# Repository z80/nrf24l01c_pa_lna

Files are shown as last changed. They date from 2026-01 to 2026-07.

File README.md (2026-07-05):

# Radio board with Power Amplifier.

A 2.4GHz generic radio communication board based on NRF24L01+ Nordic radio chip and RFX2101C Power Amplifier chip.

It is equipped with an on-board 3.3V linear regulator. So, it hasn't ever been noticed loosing a connection or malfunctioning due to power rail voltage fluctuations if powered with anything above 3.7V.

Thermal design turned out to be good. At max power and constant carrier mode the board consumes ~200mA of current. But neither part gets hot. The whole board heats up evenly and is just warm on touch.

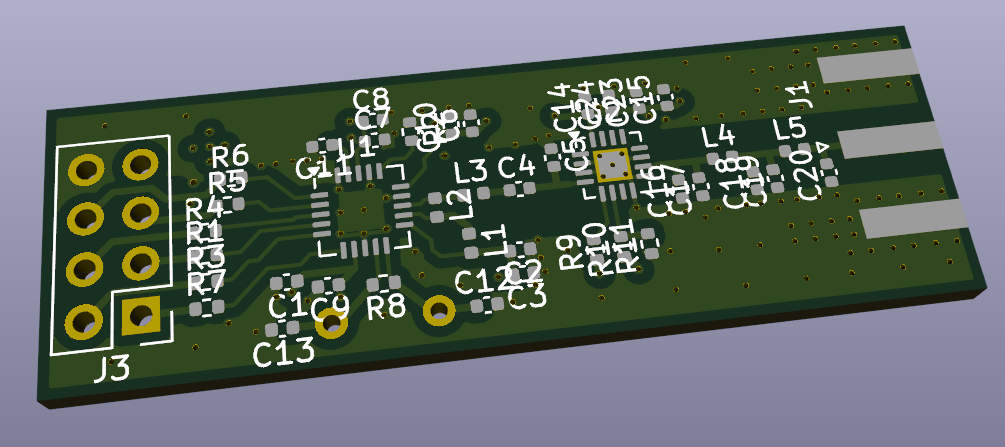
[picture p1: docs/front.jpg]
front

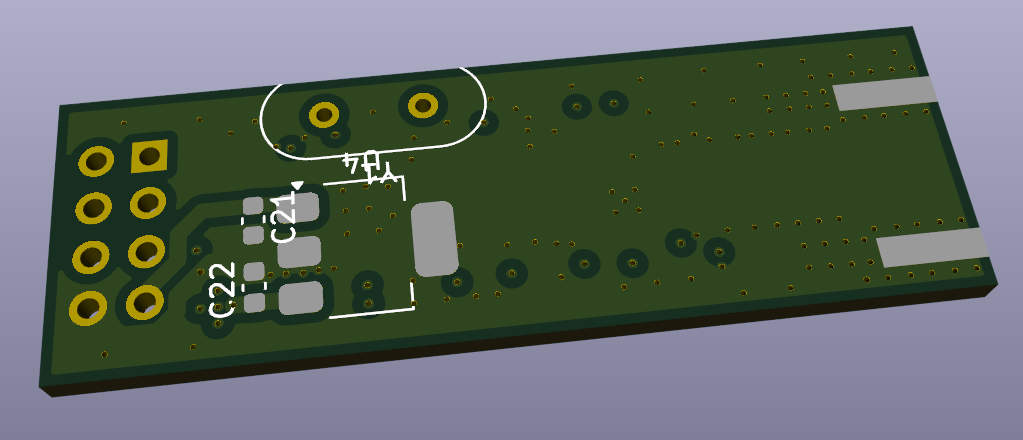
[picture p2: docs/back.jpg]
back


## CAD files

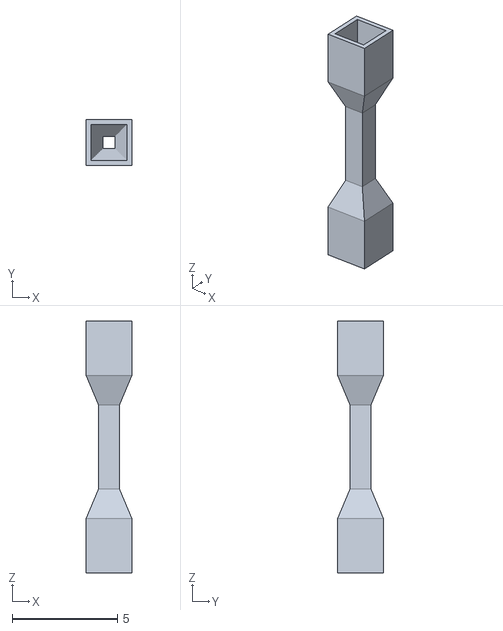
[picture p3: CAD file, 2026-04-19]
blender3d/light_stand.stl
2.17 x 2.17 x 12.0

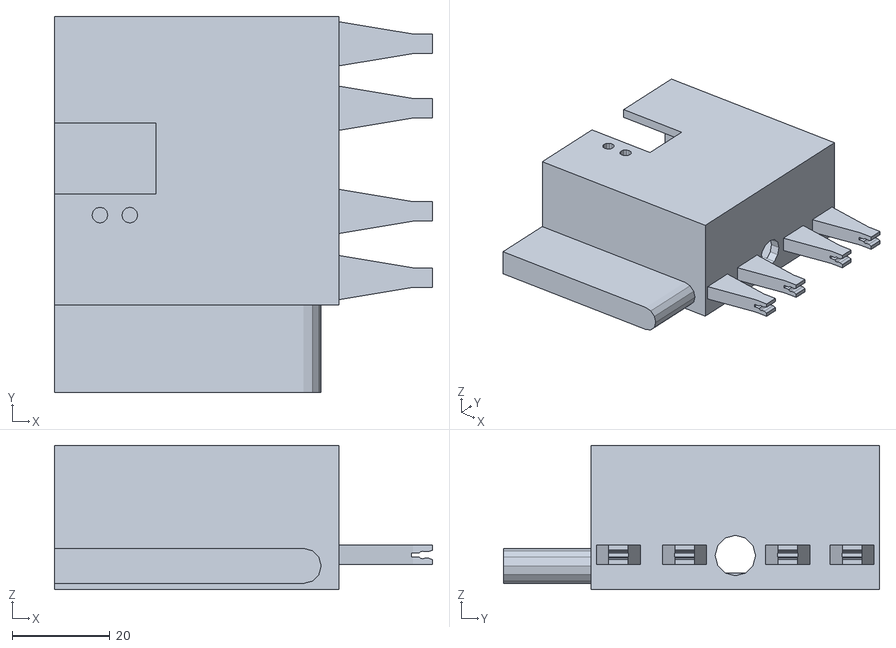
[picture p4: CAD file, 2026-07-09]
blender3d/multi/rf_outer_case.stl
77.4 x 77.1 x 29.6

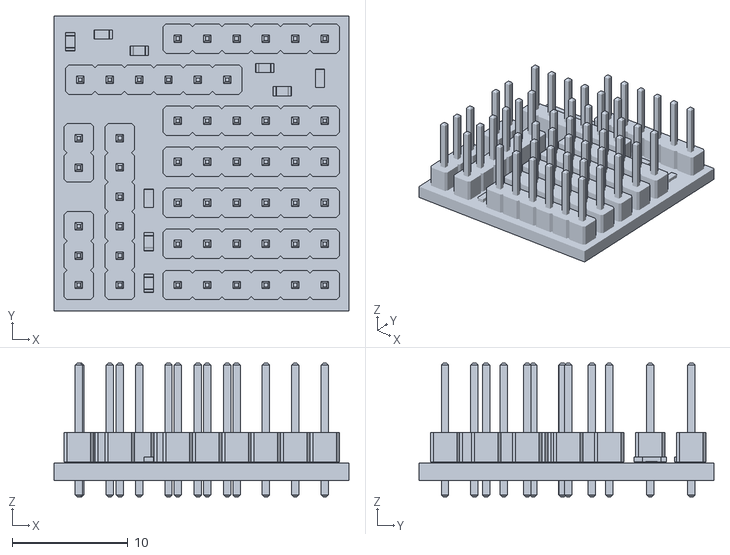
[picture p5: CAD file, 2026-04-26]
schematics/spi_split/3d/spi_split.stl
25.5 x 25.5 x 11.5

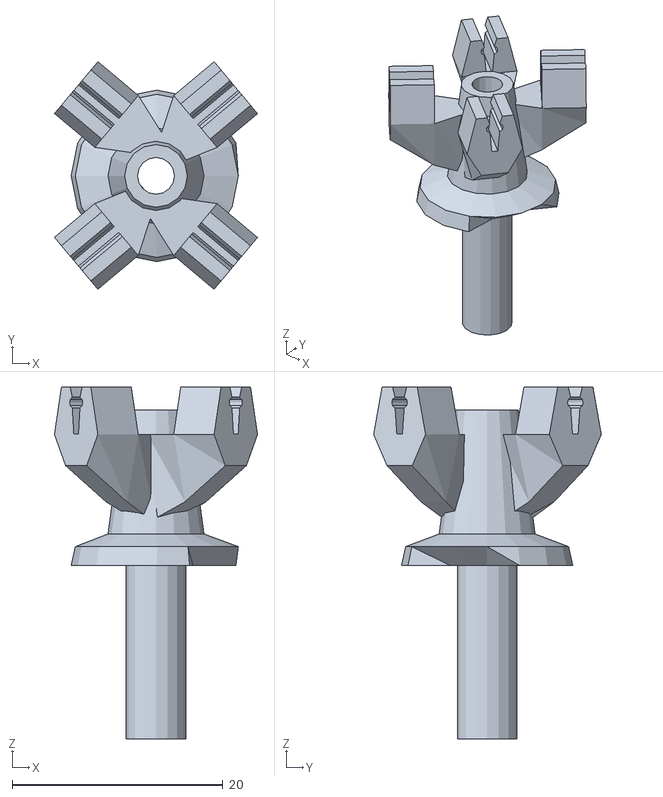
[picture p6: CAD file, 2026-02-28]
blender3d/biquad_standoff.stl
19.3 x 21.6 x 33.4

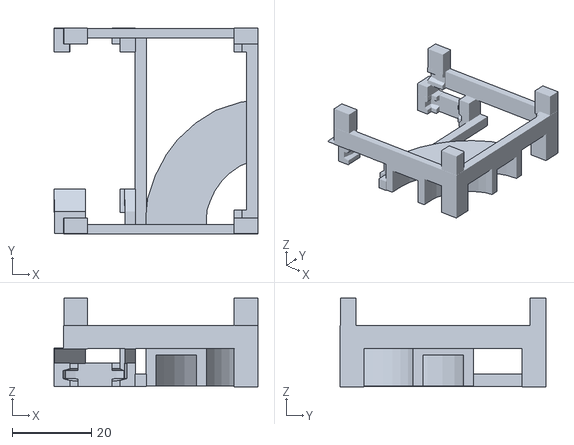
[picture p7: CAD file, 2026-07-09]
blender3d/multi/rf_inner_holder.stl
51.5 x 52.0 x 22.4

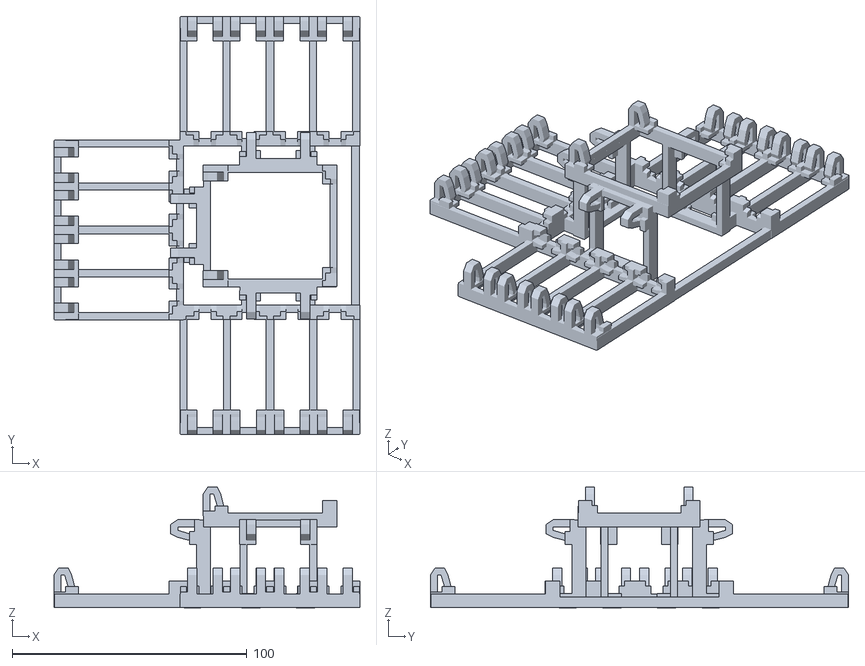
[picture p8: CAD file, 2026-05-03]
blender3d/multi/multi.stl
130.2 x 178.0 x 51.4

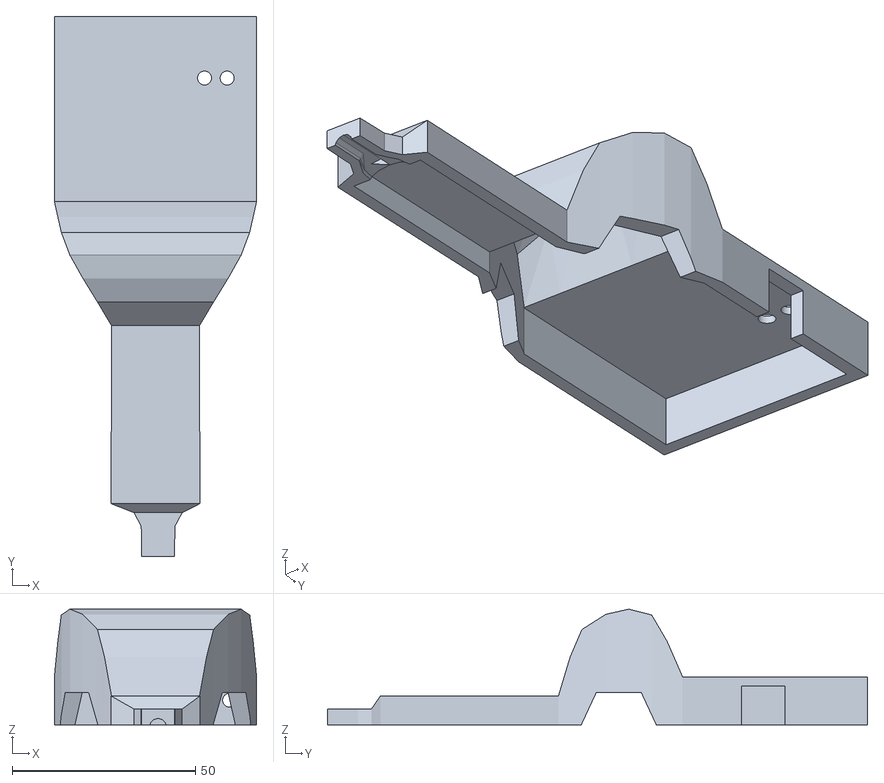
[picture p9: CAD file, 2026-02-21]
blender3d/nrf_pcb_case_upper.stl
55.1 x 147.2 x 31.5

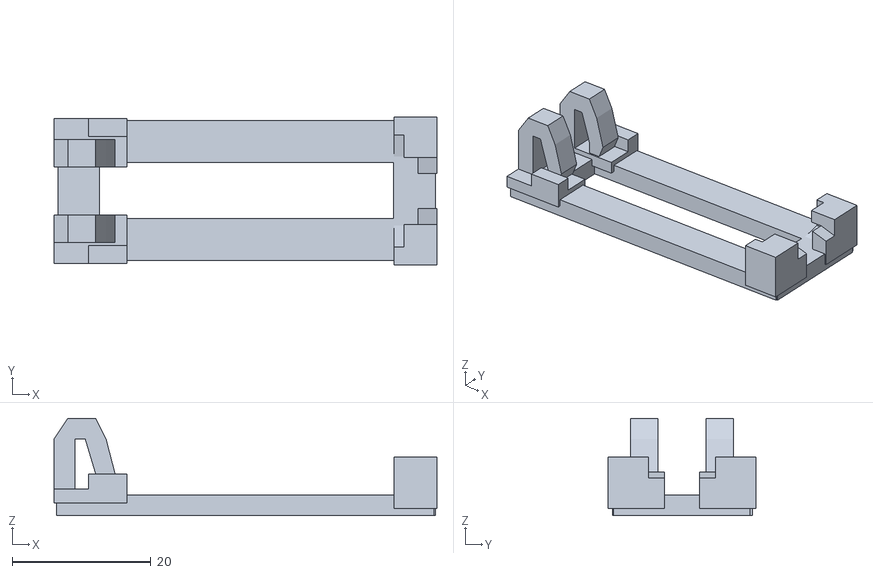
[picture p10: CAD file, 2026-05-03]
blender3d/multi/radio.stl
55.1 x 21.3 x 14.0

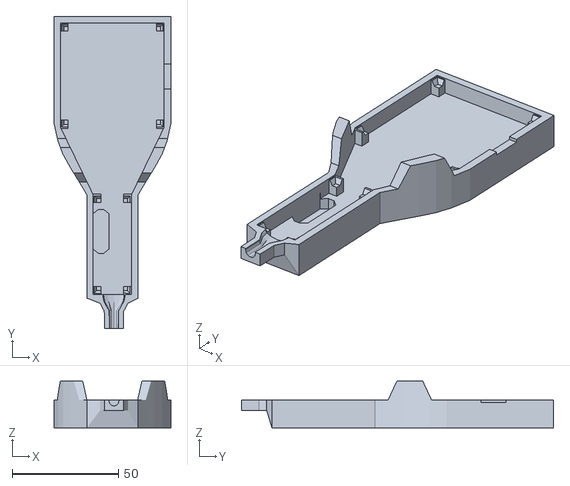
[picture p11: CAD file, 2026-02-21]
blender3d/nrf_pcb_case_lower.stl
55.1 x 147.2 x 22.1

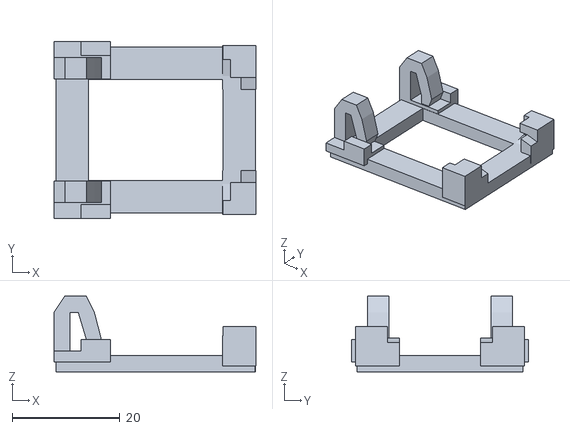
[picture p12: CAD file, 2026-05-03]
blender3d/multi/split.stl
37.5 x 32.9 x 14.0

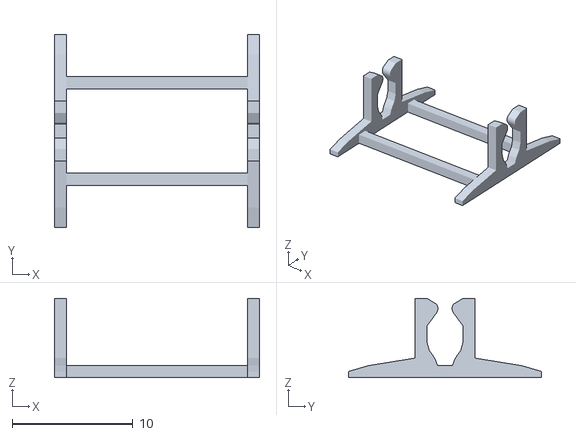
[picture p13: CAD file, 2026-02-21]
blender3d/shield_stand.stl
17.0 x 16.0 x 6.59

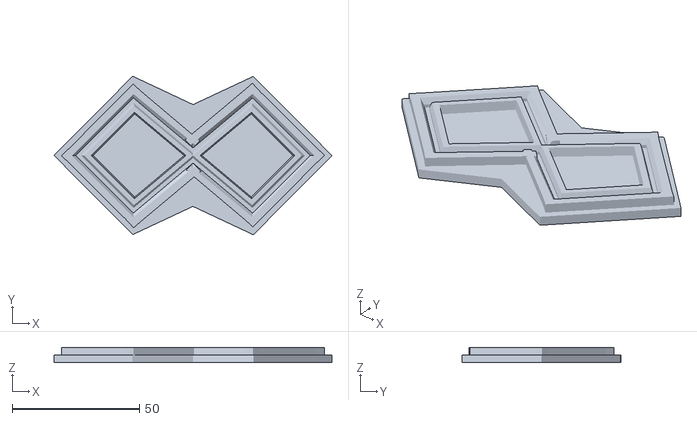
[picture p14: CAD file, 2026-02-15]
blender3d/biquad_jig.stl
109.2 x 62.3 x 5.99

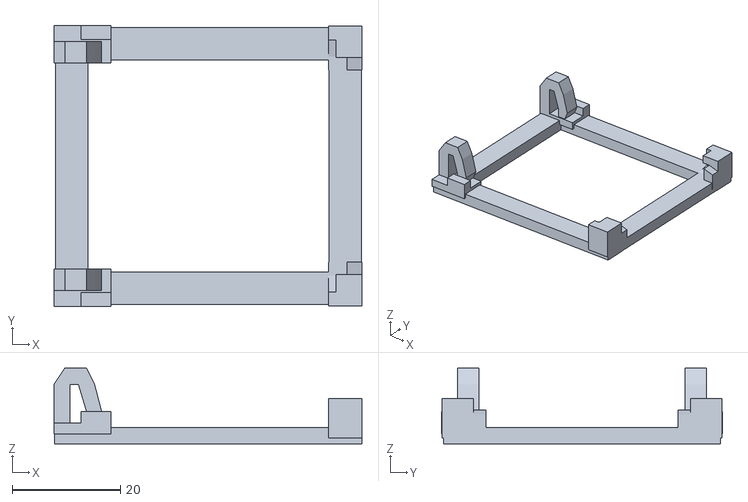
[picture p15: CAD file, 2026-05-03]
blender3d/multi/mp.stl
56.9 x 52.0 x 14.0

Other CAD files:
blender3d/biquad_jig.blend
blender3d/light_stand.blend
blender3d/multi/mp_plus_rf.blend
blender3d/multi/multi.blend
blender3d/nrf_pcb_case.blend
blender3d/shield_stand.blend

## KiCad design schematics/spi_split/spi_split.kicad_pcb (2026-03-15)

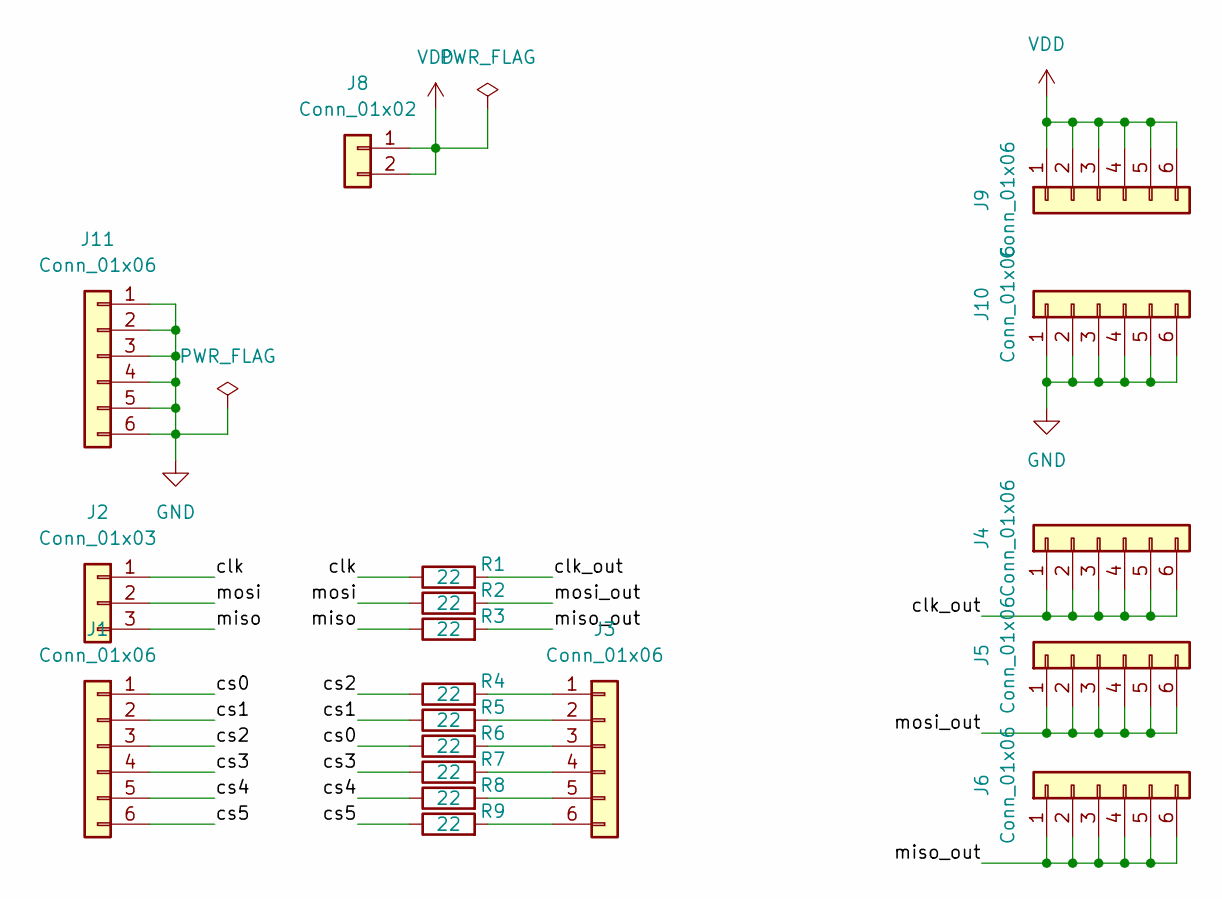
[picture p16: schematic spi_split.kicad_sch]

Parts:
J1, J3, J4, J5, J6, J9, J10, J11: Conn_01x06; PinHeader_1x06_P2.54mm_Vertical
J2: Conn_01x03; PinHeader_1x03_P2.54mm_Vertical
J8: Conn_01x02; PinHeader_1x02_P2.54mm_Vertical
R1, R2, R3, R4, R5, R6, R7, R8, R9: 22; R_0603_1608Metric

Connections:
/clk: J2.1, R1.1
/clk_out: J4.1, J4.2, J4.3, J4.4, J4.5, J4.6, R1.2
/cs0: J1.1, R6.1
/cs1: J1.2, R5.1
/cs2: J1.3, R4.1
/cs3: J1.4, R7.1
/cs4: J1.5, R8.1
/cs5: J1.6, R9.1
/miso: J2.3, R3.1
/miso_out: J6.1, J6.2, J6.3, J6.4, J6.5, J6.6, R3.2
/mosi: J2.2, R2.1
/mosi_out: J5.1, J5.2, J5.3, J5.4, J5.5, J5.6, R2.2
GND: J10.1, J10.2, J10.3, J10.4, J10.5, J10.6, J11.1, J11.2, J11.3, J11.4, J11.5, J11.6
unnamed: J3.1, R4.2
unnamed: J3.2, R5.2
unnamed: J3.3, R6.2
unnamed: J3.4, R7.2
unnamed: J3.5, R8.2
unnamed: J3.6, R9.2
VDD: J8.1, J8.2, J9.1, J9.2, J9.3, J9.4, J9.5, J9.6

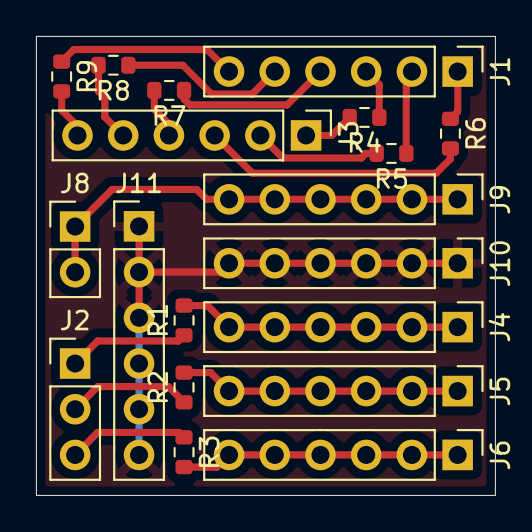
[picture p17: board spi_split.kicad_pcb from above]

Board: 2 copper layers, 25.5 x 25.5 mm, 19 parts (0 on the bottom side), 20 nets.

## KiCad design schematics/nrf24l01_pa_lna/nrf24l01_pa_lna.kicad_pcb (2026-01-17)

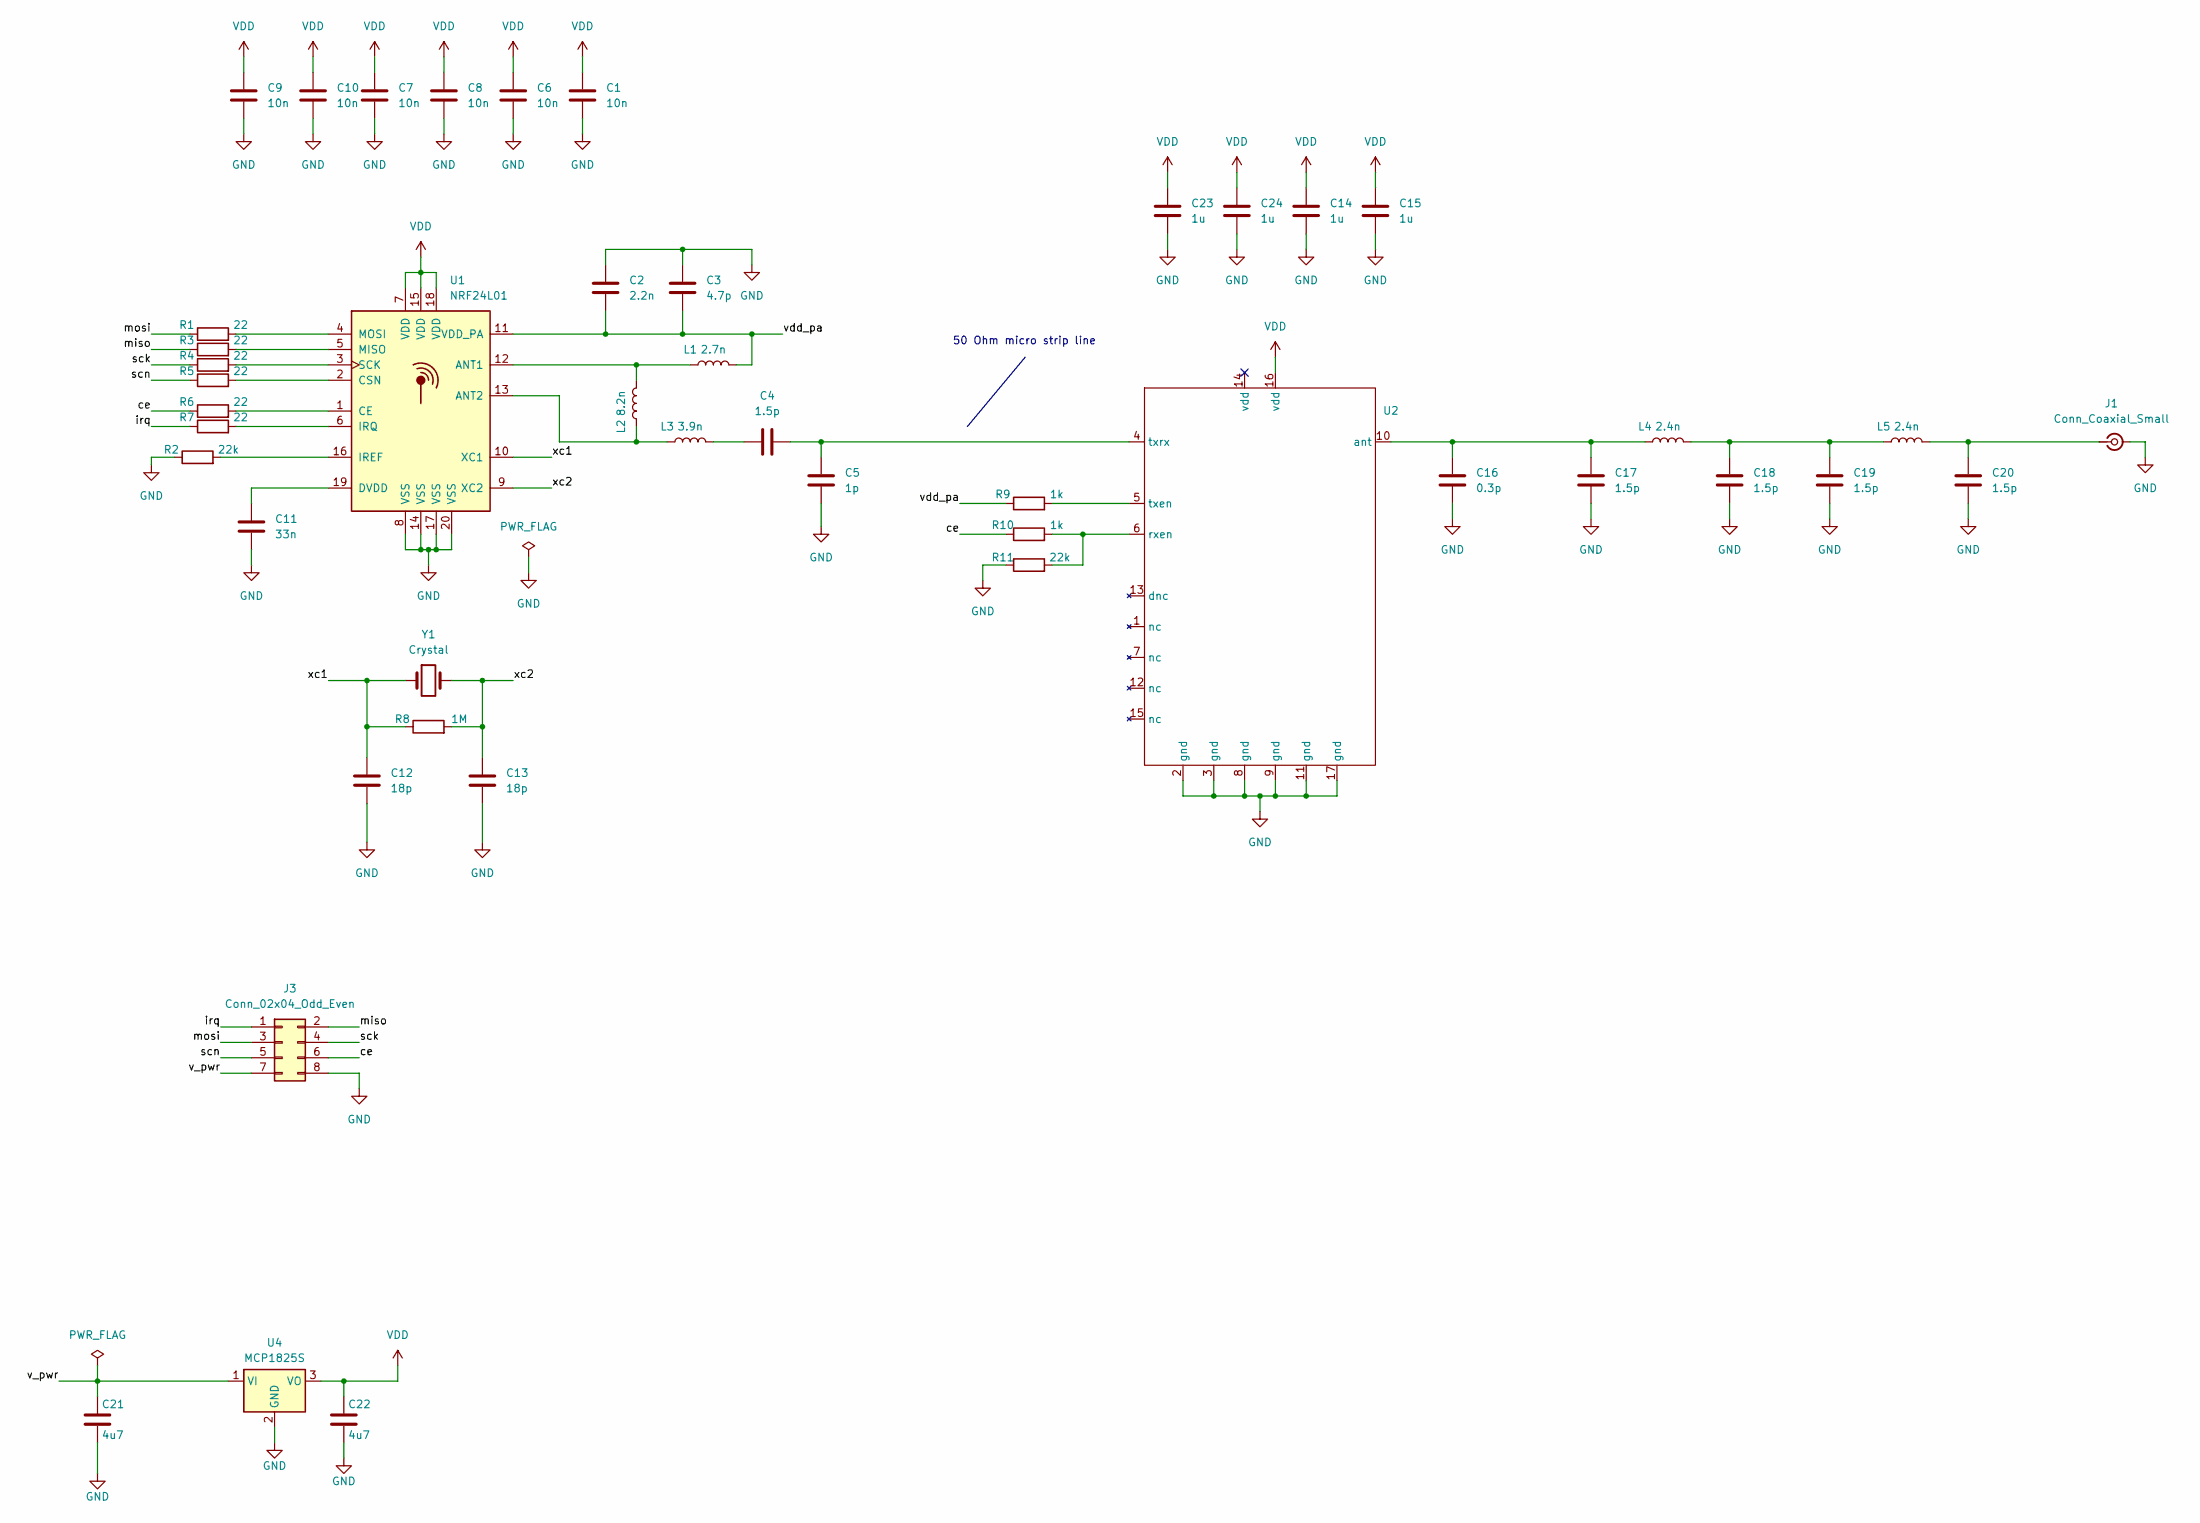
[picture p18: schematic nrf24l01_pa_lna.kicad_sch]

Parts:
C1, C6, C7, C8, C9, C10: 10n; C_0402_1005Metric
C2: 2.2n; C_0402_1005Metric
C3: 4.7p; C_0402_1005Metric
C4, C17, C18, C19, C20: 1.5p; C_0402_1005Metric
C5: 1p; C_0402_1005Metric
C11: 33n; C_0402_1005Metric
C12, C13: 18p; C_0402_1005Metric
C14, C15, C23, C24: 1u; C_0402_1005Metric
C16: 0.3p; C_0402_1005Metric
C21, C22: 4u7; C_0603_1608Metric
J1: Conn_Coaxial_Small; SMA_Amphenol_132289_EdgeMount
J3: Conn_02x04_Odd_Even; PinHeader_2x04_P2.54mm_Vertical
L1: 2.7n; L_0402_1005Metric
L2: 8.2n; L_0402_1005Metric
L3: 3.9n; L_0402_1005Metric
L4, L5: 2.4n; L_0402_1005Metric
R1, R3, R4, R5, R6, R7: 22; R_0402_1005Metric
R2, R11: 22k; R_0402_1005Metric
R8: 1M; R_0402_1005Metric
R9, R10: 1k; R_0402_1005Metric
U1: NRF24L01; QFN-20-4x4mm_P0.5mm_EP2.5x2.5mm
U2: LQFN-16-1EP_3x3mm_P0.5mm_EP1.7x1.7mm
U4: MCP1825S; SOT-223-3_TabPin2
Y1: Crystal; Crystal_HC18-U_Vertical

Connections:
/ce: J3.6, R6.1, R10.1
/irq: J3.1, R7.1
/miso: J3.2, R3.1
/mosi: J3.3, R1.1
/sck: J3.4, R4.1
/scn: J3.5, R5.1
/v_pwr: C21.1, J3.7, U4.1 (VI)
/vdd_pa: C2.2, C3.2, L1.2, R9.1, U1.11 (VDD_PA)
/xc1: C12.1, R8.1, U1.10 (XC1), Y1.1
/xc2: C13.1, R8.2, U1.9 (XC2), Y1.2
GND: C1.2, C2.1, C3.1, C5.1, C6.2, C7.2, C8.2, C9.2, C10.2, C11.2, C12.2, C13.2, C14.2, C15.2, C16.1, C17.1, C18.1, C19.1, C20.1, C21.2, C22.2, C23.2, C24.2, J1.2 (Ext), J3.8, R2.1, R11.1, U1.8 (VSS), U1.14 (VSS), U1.17 (VSS), U1.20 (VSS), U2.2 (gnd), U2.3 (gnd), U2.8 (gnd), U2.9 (gnd), U2.11 (gnd), U2.17 (gnd), U4.2 (GND)
unnamed: C4.1, L3.2
unnamed: C18.2, C19.2, L4.2, L5.1
unnamed: C20.2, J1.1 (In), L5.2
unnamed: L1.1, L2.2, U1.12 (ANT1)
unnamed: L2.1, L3.1, U1.13 (ANT2)
unnamed: R6.2, U1.1 (CE)
unnamed: R5.2, U1.2 (CSN)
unnamed: C11.1, U1.19 (DVDD)
unnamed: R2.2, U1.16 (IREF)
unnamed: R7.2, U1.6 (IRQ)
unnamed: R3.2, U1.5 (MISO)
unnamed: R1.2, U1.4 (MOSI)
unnamed: R4.2, U1.3 (SCK)
unnamed: C16.2, C17.2, L4.1, U2.10 (ant)
unnamed: R10.2, R11.2, U2.6 (rxen)
unnamed: R9.2, U2.5 (txen)
unnamed: C4.2, C5.2, U2.4 (txrx)
VDD: C1.1, C6.1, C7.1, C8.1, C9.1, C10.1, C14.1, C15.1, C22.1, C23.1, C24.1, U1.7 (VDD), U1.15 (VDD), U1.18 (VDD), U2.16 (vdd), U4.3 (VO)

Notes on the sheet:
50 Ohm micro strip line

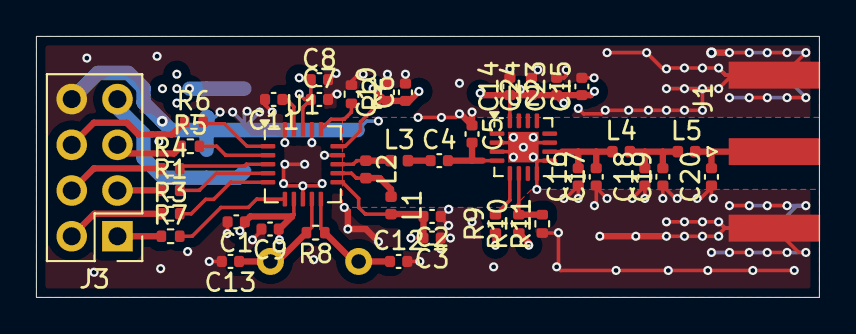
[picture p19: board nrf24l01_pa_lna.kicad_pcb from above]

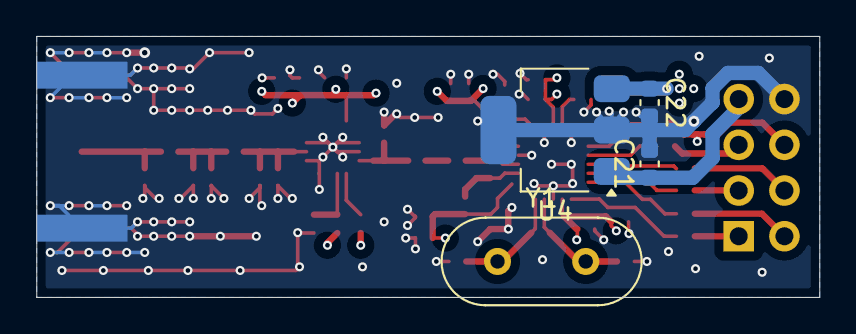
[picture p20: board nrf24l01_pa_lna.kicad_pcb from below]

Board: 4 copper layers, 43.5 x 14.5 mm, 46 parts (4 on the bottom side), 29 nets.

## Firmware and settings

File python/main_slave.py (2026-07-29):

import asyncio
import gc
from transport_node import TransportNode

class SlaveNode(TransportNode):

    async def on_command(self, src_id, command):
        print("RX", src_id, command)
        ret = {
            "slave_response": "all good",
        }
        return ret

    async def periodic_task(self):
        # Wait until enumeration is complete
        while self.node_id is None:
            print("WAIT enum")
            await asyncio.sleep(2)

        print("ID", self.node_id)
        print("LOOP start")

        while True:
            try:
                # Ask master how many nodes exist
                qty = await self.get_nodes_qty()
                print("NODES", qty)

                # Query each node
                for idx in range(qty):
                    info = await self.get_node_info(idx)
                    print("INFO", idx, info)

                    node_id = info.get("id")
                    if node_id is None:
                        print("SKIP no-id", idx)
                        continue
                    if node_id == self.node_id:
                        print("SKIP self", node_id)
                        continue
                    
                    free_bytes = gc.mem_free()
                    cmd = {
                        "cmd": "ping",
                        "from": self.node_id,
                        "to": node_id,
                        "message": "Hello from slave {}".format(self.node_id), 
                        "slave free bytes": free_bytes
                    }

                    print("TX", node_id, cmd)

                    try:
                        reply = await self.send_command_and_wait_reply(node_id, cmd)
                        print("REPLY", node_id, reply)
                    except Exception as e:
                        print("NOREPLY", node_id, e)

            except Exception as e:
                print("LOOP!", e)

            await asyncio.sleep(5)  # repeat every 5 seconds


async def async_main():
    tr = SlaveNode()

    # Start periodic task
    #asyncio.create_task(tr.periodic_task())

    # Main processing loop
    await tr.process()


def main():
    asyncio.run(async_main())


main()

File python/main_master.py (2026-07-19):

import asyncio
import gc

from transport_node import TransportNode

class MasterNode(TransportNode):

    async def on_command( self, src_id, command ):
        print("RX", src_id, command)
        free_bytes = gc.mem_free()
        ret = { "master free mem": free_bytes }
        return ret


async def async_main():
    tr = MasterNode(is_master=True)

    await tr.process()


def main():
    asyncio.run(async_main())


main()

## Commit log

2026-01-14 Designing the schematic and picking specific components.
    [nrf24l01_pa_lna.kicad_sch]
2026-01-14 Power flags to avoid KiCad errors.
    [nrf24l01_pa_lna.kicad_sch]
2026-01-14 Placing elements, making connections.
    [nrf24l01_pa_lna.kicad_pcb, nrf24l01_pa_lna.kicad_sch]
2026-01-15 Finished the design in bulk...
    [nrf24l01_pa_lna.kicad_pcb, nrf24l01_pa_lna.kicad_sch]
2026-01-17 May be good enough?
    [nrf24l01_pa_lna.kicad_pcb]
2026-01-19 Generated interactive BOM.
2026-01-19 Making antenna jig.
    [biquad_jig.blend]
2026-01-19 Jig and spacer.
    [biquad_jig.blend]
2026-02-11 Downloaded a python driver for NRF32L01. The bring up tests.
2026-02-15 A fix plus needed functionality.
    [nrf24l01.py]
2026-02-15 Jig STL files.
    [biquad_jig.blend, biquad_jig.stl, biquad_standoff.stl]
2026-02-16 Constant carrier with changing channel also runs. At max power the board gets warm, but not hot.
2026-02-21 Making cases.
    [nrf_pcb_case.blend, shield_stand.blend, shield_stand.stl]
2026-02-21 PCB case.
    [nrf_pcb_case.blend, nrf_pcb_case_lower.stl, nrf_pcb_case_upper.stl]
2026-02-28 Adjustments to the standoff design.
    [biquad_jig.blend, biquad_standoff.stl]
2026-03-01 Forgot to import Pin from pyb.
2026-03-15 Board for splitting SPI to multiple slaves, up to 6 slave boards.
    [spi_split.kicad_pcb, spi_split.kicad_sch]
2026-03-15 Light stand. This is unrelated. Just put it here.
    [light_stand.blend, light_stand.stl]
2026-03-22 Generated BOM for the SPI split board.
2026-04-28 Desnging board mounts.
    [multi.blend]
2026-05-14 Modified driver to have an option to instantiate it a few times with different pins but the same SPI.
2026-05-16 With insert.
    [light_stand.blend]
2026-05-18 Joint light stand.
    [light_stand.blend]
2026-05-18 This way it works. Need to initialize all the pins such that neither CS pin is low.
2026-07-05 Designing a case for the radio.
    [mp_plus_rf.blend]
2026-07-05 First version to be tried.
    [mp_plus_rf.blend]
2026-07-05 PCB holder 2-d attempt.
    [mp_plus_rf.blend]
2026-07-09 Case for the single one.
    [mp_plus_rf.blend, rf_inner_holder.stl, rf_outer_case.stl]
2026-07-09 Tests for the one board attached.
2026-07-12 A prototype for a netowrk of nodes.
2026-07-18 Modification. But it doesn't seem fixing the problem entirely.
    [transport_node.py]
2026-07-18 Trying to eliminate periodic errors by changing the logic.
    [nrf24l01.py, test_transport_node.py, transport_node.py]
2026-07-18 A physical delay so that the requestee has a change to switch to reception mode.
2026-07-29 Replaced python crc with C wrapper CRC.
    [transport_node.py]
2026-08-03 Transport node with radio power levels.
